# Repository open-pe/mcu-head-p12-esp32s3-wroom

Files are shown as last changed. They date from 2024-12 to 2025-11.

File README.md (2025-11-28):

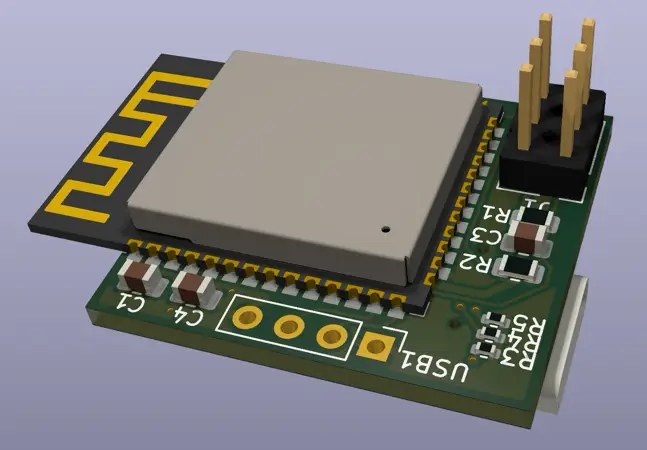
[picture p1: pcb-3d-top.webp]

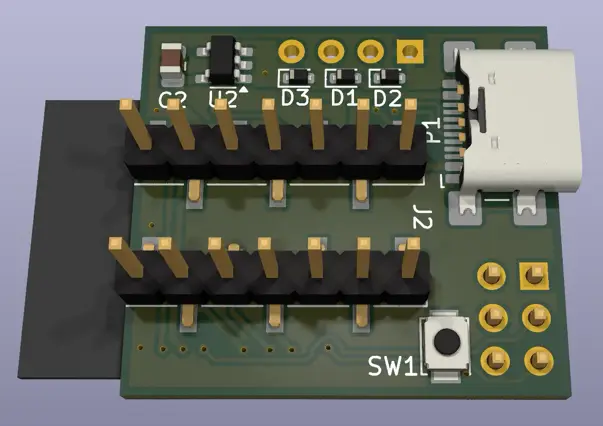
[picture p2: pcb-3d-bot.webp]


This is a break-out for an ESP32-WROOM or ESP32S3-WROOM module.
These modules can be hard to desolder, if the chip gets damaged during development.
You can mount this break-out board using 2.54mm pitch standard pin connectors (SMD) on a mainboard for easier
replacement.

The footprint of the landing connector on the mainboard fits inside the WROOM-Footprint so it does not need extra space
on the mainboard (only wiring due to the extra pads can be a bit more complicated).
During assembly you can either populate the WROOM module directly on the mainboard or use this break-out board.

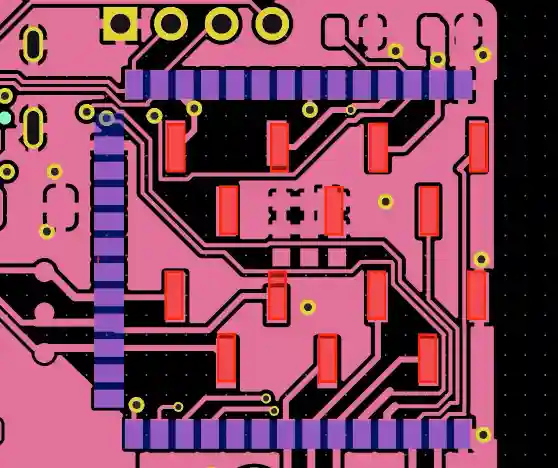
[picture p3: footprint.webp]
footprint
|                                           |
|--------------------------------------------------------------------------------------------------|
| blue: WROOM footprint pads <br/>red: 2.54mm SMD pin header pads to receive this break-out board. |

It also works on solderless breadboards.

## Features
* ESP-PROG header
* USB pin header
* USB-C socket
* BOOT button (GPIO0) to enter download mode manually
* 3.3V LDO regulator

# Notes

## LDOs 5V to 3.3V

* NCP167BMX330TBG
* TLV70233_SOT23-5

## 3.3-5V boost

if we put the ESP32S3 in USB host mode and supply 5V on the USB-C port we can connect arbitrary usb devices.
[digikey boost](https://www.digikey.de/short/q9n4rhhj)

* TPS631000DRLR
* TPS61094 (bi-directional) kicad symbol: https://github.com/JY68-Werable-EEG-Sensor/Wearable-EEG-Sensor
    * this might replace the 5V to 3.3V LDO.

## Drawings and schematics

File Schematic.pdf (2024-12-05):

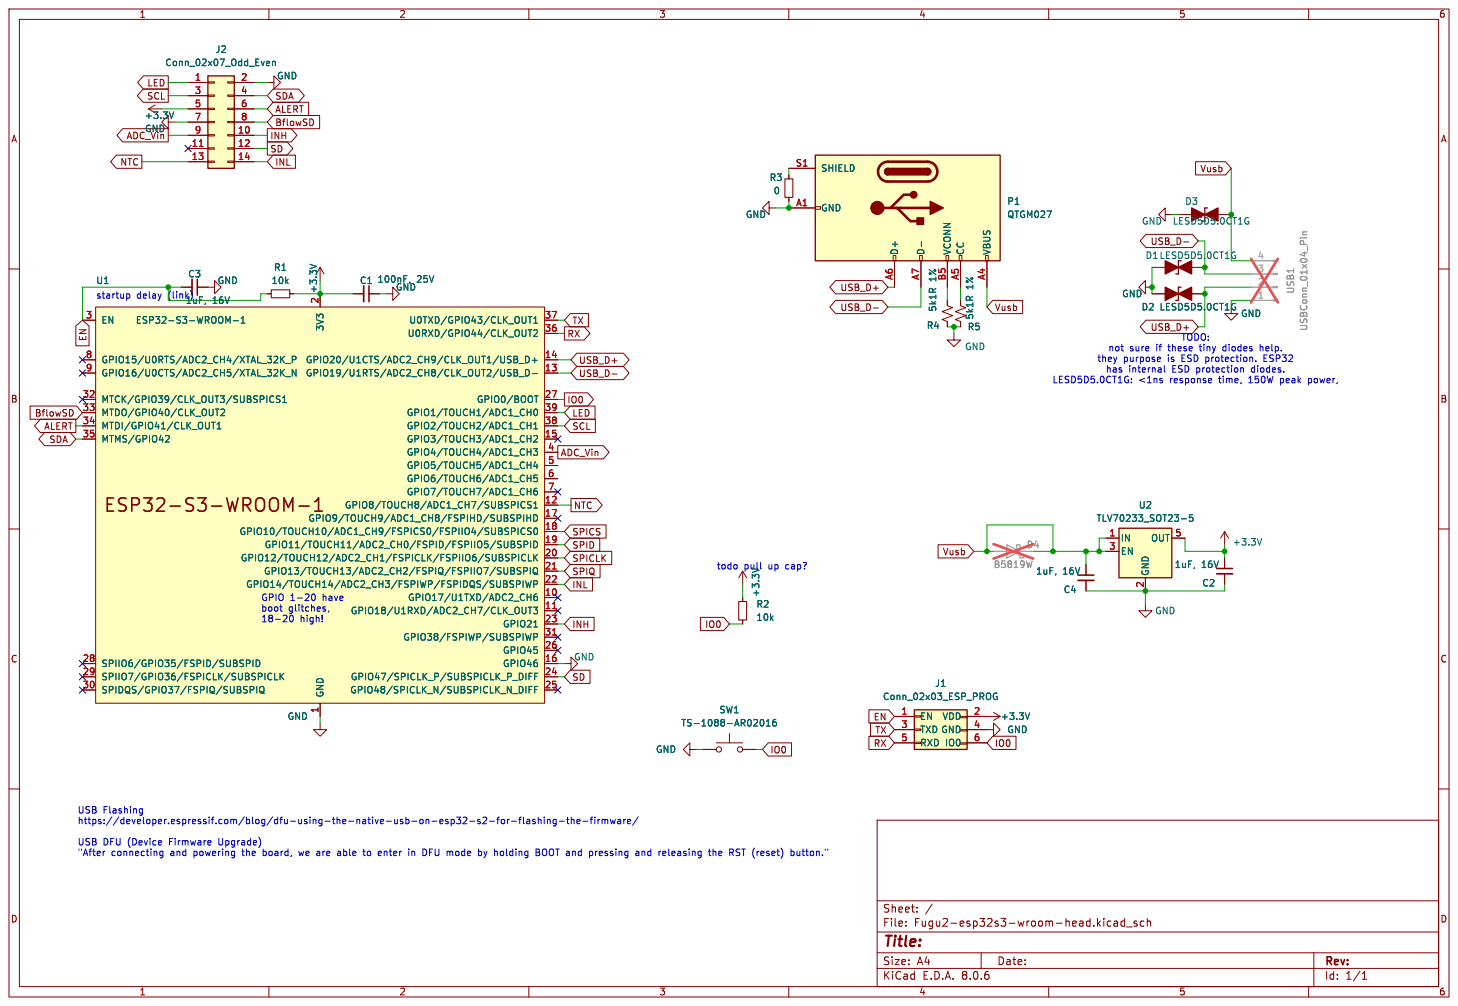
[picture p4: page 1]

2 GPIO12/TOUCH12/ADC2_CH1/FSPICLK/FSPIIO6/SUBSPICLK 20 GPIO13/TOUCH13/ADC2_CH2/FSPIQ/FSPIIO7/SUBSPIQ 21 GPIO14/TOUCH14/ADC2_CH3/FSPIWP/FSPIDQS/SUBSPIWP 22 GPIO21 23 GPIO47/SPICLK_P/SUBSPICLK_P_DIFF 24 GPIO48/SPICLK_N/SUBSPICLK_N_DIFF 25 GPIO45 26 GPIO0/BOOT 27 SPIIO6/GPIO35/FSPID/SUBSPID 28 SPIIO7/GPIO36/FSPICLK/SUBSPICLK 29 EN 3 SPIDQS/GPIO37/FSPIQ/SUBSPIQ 30 GPIO38/FSPIWP/SUBSPIWP 31 MTCK/GPIO39/CLK_OUT3/SUBSPICS1 32 MTDO/GPIO40/CLK_OUT2 33 MTDI/GPIO41/CLK_OUT1 34 MTMS/GPIO42 35 U0RXD/GPIO44/CLK_OUT2 36 U0TXD/GPIO43/CLK_OUT1 37 GPIO2/TOUCH2/ADC1_CH1 38 GPIO1/TOUCH1/ADC1_CH0 39 GPIO4/TOUCH4/ADC1_CH3 4 GPIO5/TOUCH5/ADC1_CH4 5 GPIO6/TOUCH6/ADC1_CH5 6 GPIO7/TOUCH7/ADC1_CH6 7 GPIO15/U0RTS/ADC2_CH4/XTAL_32K_P 8 GPIO16/U0CTS/ADC2_CH5/XTAL_32K_N 9 U1 ESP32-S3-WROOM-1 GND

2 GPIO12/TOUCH12/ADC2_CH1/FSPICLK/FSPIIO6/SUBSPICLK 20 GPIO13/TOUCH13/ADC2_CH2/FSPIQ/FSPIIO7/SUBSPIQ 21 GPIO14/TOUCH14/ADC2_CH3/FSPIWP/FSPIDQS/SUBSPIWP 22 GPIO21 23 GPIO47/SPICLK_P/SUBSPICLK_P_DIFF 24 GPIO48/SPICLK_N/SUBSPICLK_N_DIFF 25 GPIO45 26 GPIO0/BOOT 27 SPIIO6/GPIO35/FSPID/SUBSPID 28 SPIIO7/GPIO36/FSPICLK/SUBSPICLK 29 EN 3 SPIDQS/GPIO37/FSPIQ/SUBSPIQ 30 GPIO38/FSPIWP/SUBSPIWP 31 MTCK/GPIO39/CLK_OUT3/SUBSPICS1 32 MTDO/GPIO40/CLK_OUT2 33 MTDI/GPIO41/CLK_OUT1 34 MTMS/GPIO42 35 U0RXD/GPIO44/CLK_OUT2 36 U0TXD/GPIO43/CLK_OUT1 37 GPIO2/TOUCH2/ADC1_CH1 38 GPIO1/TOUCH1/ADC1_CH0 39 GPIO4/TOUCH4/ADC1_CH3 4 GPIO5/TOUCH5/ADC1_CH4 5 GPIO6/TOUCH6/ADC1_CH5 6 GPIO7/TOUCH7/ADC1_CH6 7 GPIO15/U0RTS/ADC2_CH4/XTAL_32K_P 8 GPIO16/U0CTS/ADC2_CH5/XTAL_32K_N 9 GND

1 GPIO17/U1TXD/ADC2_CH6 10 GPIO18/U1RXD/ADC2_CH7/CLK_OUT3 11 GPIO8/TOUCH8/ADC1_CH7/SUBSPICS1 12 GPIO19/U1RTS/ADC2_CH8/CLK_OUT2/USB_D- 13 GPIO20/U1CTS/ADC2_CH9/CLK_OUT1/USB_D+ 14 GPIO3/TOUCH3/ADC1_CH2 15 GPIO46 16 GPIO9/TOUCH9/ADC1_CH8/FSPIHD/SUBSPIHD 17 GPIO10/TOUCH10/ADC1_CH9/FSPICS0/FSPIIO4/SUBSPICS0 18 GPIO11/TOUCH11/ADC2_CH0/FSPID/FSPIIO5/SUBSPID 19 3V3

Id: 1/1 Title: File: Fugu2-esp32s3-wroom-head.kicad_sch Sheet: / GND

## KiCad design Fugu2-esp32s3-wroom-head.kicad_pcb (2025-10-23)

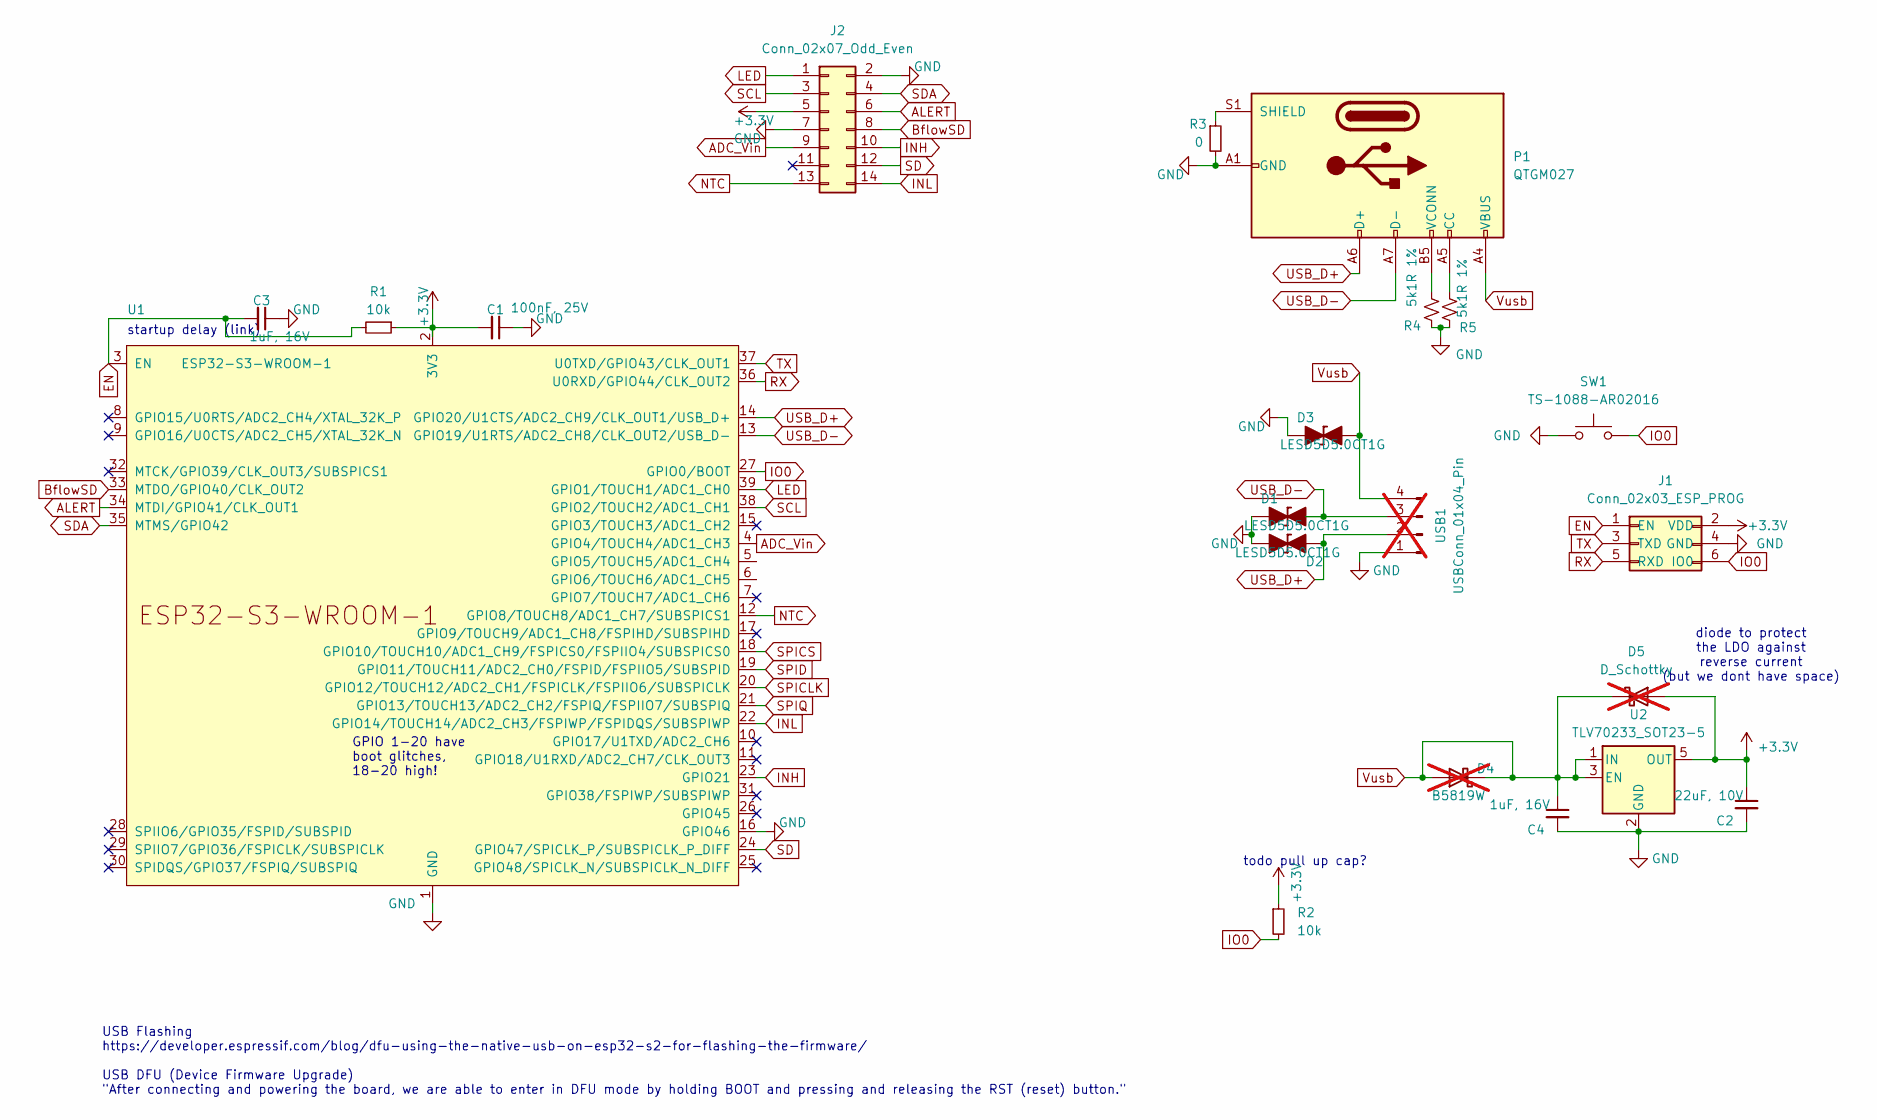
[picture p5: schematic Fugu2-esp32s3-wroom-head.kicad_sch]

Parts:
C1: 100nF, 25V; C_0805_2012Metric; MPN 100nF
C2: 22uF, 10V; C_0603_1608Metric_Pad1.08x0.95mm_HandSolder; MPN 1uF, 16V; Digikey CL10A226MP8NUNE
C3, C4: 1uF, 16V; C_0805_2012Metric; MPN 1uF, 16V
D1, D2, D3: LESD5D5.0CT1G; D_SOD-523; MPN LESD5D5.0CT1G; LCSC C383211
D4: B5819W; D_SOD-123; MPN DNP; LCSC C8598; not fitted
D5: D_Schottky; D_SOD-123; not fitted
J1: Conn_02x03_ESP_PROG; PinHeader_2x03_P2.54mm_Vertical; MPN DNP
J2: Conn_02x07_Odd_Even; PinHeader_2x07_P2.54mm_Vertical_SMD_Pin1Left_1; MPN Samtec SSM-107-L-SV; LCSC C7017504, Samtec SSM-107-L-SV
P1: QTGM027; USB_C_Receptacle_GCT_USB4110; MPN SHOU HAN TYPE-C 16P QTGM027; LCSC C2681552
R1, R2: 10k; R_0805_2012Metric; MPN 10k
R3: 0; R_0402_1005Metric; MPN 0; LCSC C17168
R4, R5: 5k1R 1%; R_0402_1005Metric; MPN 5k1R 1%; LCSC C25905
SW1: TS-1088-AR02016; SW_Push_SPST_NO_Alps_SKRK; MPN XUNPU TS-1088-AR02016; LCSC C720477
U1: ESP32-S3-WROOM-1; ESP32-S3-WROOM-1-noPIN15; MPN ESP32-S3-WROOM-1U-N4
U2: TLV70233_SOT23-5; SOT-23-5; MPN TLV70233DBVR; LCSC C26833
USB1: USBConn_01x04_Pin; PinHeader_1x04_P2.54mm_Vertical; MPN DNP; not fitted

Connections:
+3.3V: C1.2, C2.1, D5.2 (A), J1.2 (VDD), J2.5, R1.1, R2.1, U1.2 (3V3), U2.5 (OUT)
ADC_Vin: J2.9, U1.4 (GPIO4/TOUCH4/ADC1_CH3)
ALERT: J2.6, U1.34 (MTDI/GPIO41/CLK_OUT1)
BflowSD: J2.8, U1.33 (MTDO/GPIO40/CLK_OUT2)
EN: C3.2, J1.1 (EN), R1.2, U1.3 (EN)
GND: C1.1, C2.2, C3.1, C4.2, D1.2 (A), D2.2 (A), D3.2 (A), J1.4 (GND), J2.2, J2.7, P1.A1 (GND), P1.A12 (GND), P1.B1 (GND), P1.B12 (GND), R3.2, R4.2, R5.2, SW1.1, U1.1 (GND), U1.16 (GPIO46), U1.40 (GND), U1.41 (GND), U2.2 (GND), USB1.1
INH: J2.10, U1.23 (GPIO21)
INL: J2.14, U1.22 (GPIO14/TOUCH14/ADC2_CH3/FSPIWP/FSPIDQS/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)
IO0: J1.6 (IO0), R2.2, SW1.2, U1.27 (GPIO0/BOOT)
LED: J2.1, U1.39 (GPIO1/TOUCH1/ADC1_CH0)
NTC: J2.13, U1.12 (GPIO8/TOUCH8/ADC1_CH7/SUBSPICS1)
unnamed: P1.A5 (CC), R5.1
unnamed: P1.S1 (SHIELD), R3.1
unnamed: P1.B5 (VCONN), R4.1
RX: J1.5 (RXD), U1.36 (U0RXD/GPIO44/CLK_OUT2)
SCL: J2.3, U1.38 (GPIO2/TOUCH2/ADC1_CH1)
SD: J2.12, U1.24 (GPIO47/SPICLK_P/SUBSPICLK_P_DIFF)
SDA: J2.4, U1.35 (MTMS/GPIO42)
SPICLK: U1.20 (GPIO12/TOUCH12/ADC2_CH1/FSPICLK/FSPIIO6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)
SPICS: U1.18 (GPIO10/TOUCH10/ADC1_CH9/FSPICS0/FSPIIO4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)
SPID: U1.19 (GPIO11/TOUCH11/ADC2_CH0/FSPID/FSPIIO5/S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)
SPIQ: U1.21 (GPIO13/TOUCH13/ADC2_CH2/FSPIQ/FSPIIO7/S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)
TX: J1.3 (TXD), U1.37 (U0TXD/GPIO43/CLK_OUT1)
USB_D+: D2.1 (K), P1.A6 (D+), U1.14 (GPIO20/U1CTS/ADC2_CH9/CLK_OUT1/USB_D+), USB1.2
USB_D-: D1.1 (K), P1.A7 (D-), U1.13 (GPIO19/U1RTS/ADC2_CH8/CLK_OUT2/USB_D-), USB1.3
Vusb: C4.1, D3.1 (K), D4.1 (K), D4.2 (A), D5.1 (K), P1.A4 (VBUS), P1.A9 (VBUS), P1.B4 (VBUS), P1.B9 (VBUS), U2.1 (IN), U2.3 (EN), USB1.4

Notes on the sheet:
startup delay (link)
diode to protect the LDO against reverse current (but we dont have space)
GPIO 1-20 have boot glitches, 18-20 high!
todo pull up cap?
USB Flashing https://developer.espressif.com/blog/dfu-using-the-native-usb-on-esp32-s2-for-flashing-the-firmware/ USB DFU (Device Firmware Upgrade) "After connecting and powering the board, we are able to enter in DFU mode by holding BOOT and pressing and releasing the RST (reset) button."

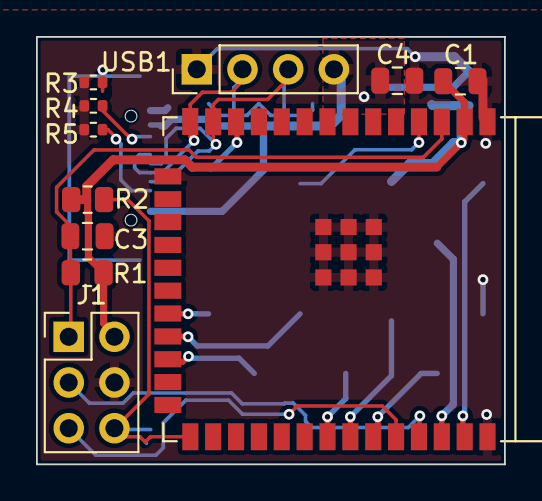
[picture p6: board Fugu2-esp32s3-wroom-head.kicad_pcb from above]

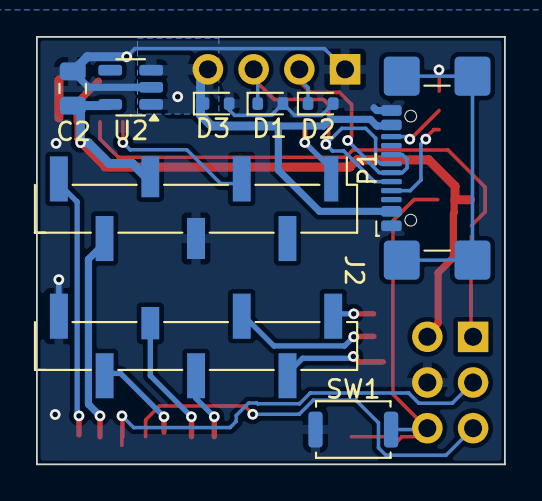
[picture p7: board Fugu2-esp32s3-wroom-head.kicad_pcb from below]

Board: 2 copper layers, 26.0 x 23.7 mm, 19 parts (8 on the bottom side), 22 nets.

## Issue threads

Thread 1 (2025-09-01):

USB-Port placement

fl4p, 2025-09-01:
The current USB-Port placement is not ideal.
The board is likely to be mounted on the motherboard so that the antenna is close to the edge of the motherboard and close to the enclosure.
The USB-ports points to the opposite direction

fl4p, 2025-10-02:
Using the 2.54 pin header USB works fine

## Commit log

2024-11-03 Intial commit
    [Fugu2-esp32s3-wroom-head.kicad_pcb, Fugu2-esp32s3-wroom-head.kicad_sch]
2024-11-07 add 3d renderings
    [Fugu2-esp32s3-wroom-head.kicad_pcb]
2024-11-07 add schematic
2024-12-05 fix button
    [Fugu2-esp32s3-wroom-head.kicad_pcb, Fugu2-esp32s3-wroom-head.kicad_sch]
2025-09-25 bump kicad version
    [Fugu2-esp32s3-wroom-head.kicad_pcb]
2025-11-28 add footprint image
